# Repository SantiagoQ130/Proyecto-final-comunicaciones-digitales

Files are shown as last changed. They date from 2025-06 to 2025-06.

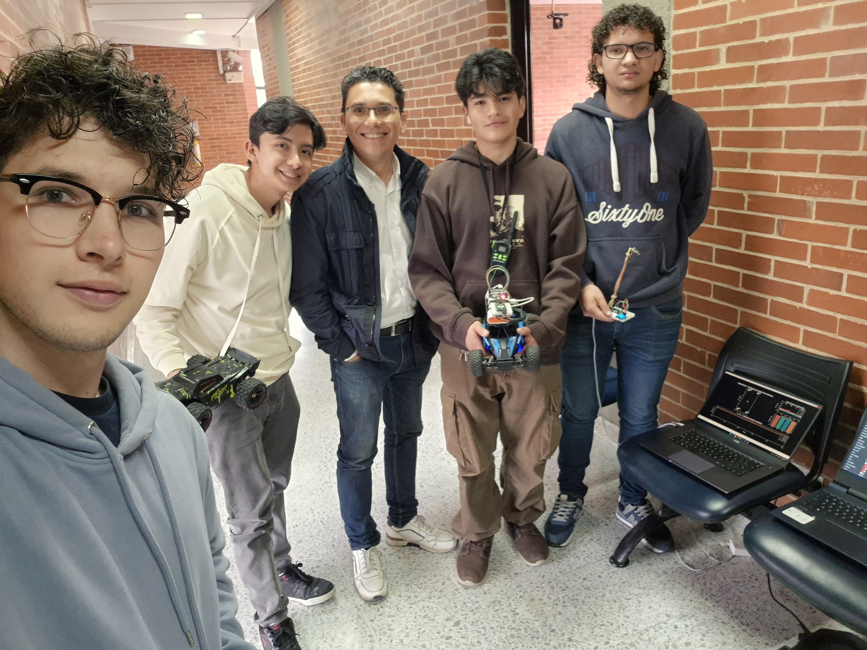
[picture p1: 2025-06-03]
Progreso/Foto.jpg

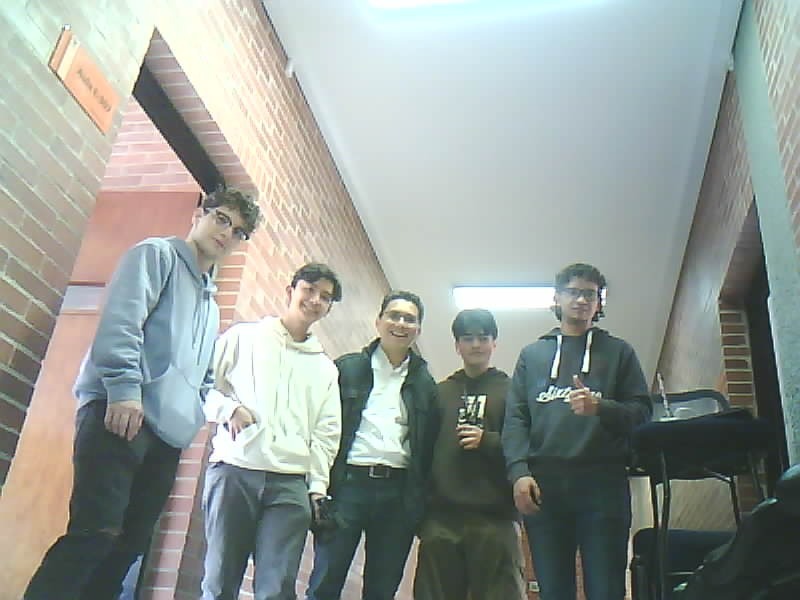
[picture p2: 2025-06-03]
Progreso/Foto carro.jpg

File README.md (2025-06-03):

# Sistema de Localización Indoor con RSSI y Sensores IMU

## 📋 Descripción del Proyecto

Este proyecto implementa un sistema de localización en interiores que utiliza mediciones de RSSI (Received Signal Strength Indicator) para determinar la posición de objetos móviles en espacios cerrados. El sistema combina múltiples tecnologías de comunicación inalámbrica para crear una red de nodos que permite la trilateración y el seguimiento de dispositivos.

## 🎯 Objetivos

- **Objetivo Principal**: Desarrollar un sistema de localización preciso para ambientes interiores donde GPS no está disponible
- **Objetivos Específicos**:
  - Implementar una red de nodos transmisores con comunicación RF (NRF24L01)
  - Crear un concentrador que recopile datos de RSSI de múltiples transmisores
  - Integrar sensores IMU 
  - Desarrollar algoritmos de trilateración para cálculo de posición
  - Crear una interfaz web para monitoreo en tiempo real

## 🏗️ Arquitectura del Sistema

### Componentes Principales

1. **Nodos Transmisores (TX1-TX4)**
   - Microcontroladores Raspberry Pi Pico W
   - Módulos NRF24L01 para comunicación RF
   - Pantallas OLED para visualización local
   - Medición de RSSI con dispositivos WiFi cercanos

2. **Concentrador/Receptor (RX)**
   - Raspberry Pi Pico W central
   - Recepción de datos de todos los transmisores
   - Procesamiento y análisis de datos RSSI
   - Interfaz de comunicación serial

3. **Nodo Principal con IMU**
   - Arduino R4 WiFi o ESP32
   - Sensor MPU6050 (acelerómetro + giroscopio)
   - Punto de acceso WiFi (Hotspot)
   - Servidor web integrado
   - Filtrado Kalman para datos del sensor
   - Esp-S3-N16R8(ESP32 S3 cam)
   - Servidor web para la camara con diferentes configuraciones
   - Reconocimiento facial

4. **Sistema de Procesamiento**
   - Algoritmos de trilateración
   - Análisis de datos en Python
   - Visualización en tiempo real

### Diagrama de Comunicación

```
[TX1] ──┐
[TX2] ──┼── NRF24L01 ──→ [RX/Concentrador] ──→ [PC/Análisis]
[TX3] ──┤                       ↕
[TX4] ──┘                   Serial/USB

[Nodo IMU] ──→ WiFi Hotspot ──→ [Dispositivos Cliente]
    ↓
[MPU6050 Sensor]
```

## 📁 Estructura del Proyecto

```
Proyecto-final-comunicaciones-digitales-main/
├── Códigos/                    # Código principal del sistema
│   ├── ArduinoR4_hotspot_MPU6050.ino    # Nodo principal con IMU
│   ├── RX_Concentrador.py               # Receptor central
│   ├── TX1.py, TX2.py, TX3.py, TX4.py  # Nodos transmisores
│   └── PicoW_Plotter_concentrador.py    # Visualización en tiempo real
├── Alternativas_hotspot/       # Implementaciones alternativas
│   ├── Esp32_hostpot.ino      # Versión ESP32
│   ├── Esp32_MPU6050_Basic.ino # ESP32 con MPU6050 básico
│   └── Esp32-s3-hotspot-mpu6050.ino # ESP32-S3 avanzado
├── Progreso/                   # Desarrollos incrementales
│   ├── trilateracion.py       # Algoritmo de trilateración
│   ├── basic_serial_reader.py # Lector serial básico
│   └── simple_serial_reader.py # Lector serial simplificado
├── datos/                      # Datos experimentales y mediciones
│   ├── Measure 1.txt          # Mediciones RSSI vs distancia
│   ├── Measure 2.txt          # Segunda serie de mediciones
│   ├── Medidas RSSI.xlsx      # Análisis estadístico
│   └── serial_reader_data.py  # Procesador de datos serie
├── Diseño PCB/                 # Diseño de PCB personalizada
│   ├── NUEVO_NODO-*.gbr       # Archivos Gerber
│   ├── NUEVO_NODO-*.drl       # Archivos de perforación
│   └── Simulación/            # Archivos de simulación
└── README.md                   # Este archivo
```

## 🛠️ Requisitos del Sistema

### Hardware Necesario

#### Para Nodos Transmisores (TX1-TX4):
- 4x Raspberry Pi Pico W
- 4x Módulo NRF24L01+
- 4x Pantalla OLED SSD1306 (128x64)
- Cables jumper y protoboard
- Fuente de alimentación 3.3V

#### Para Concentrador (RX):
- 1x Raspberry Pi Pico W
- 1x Módulo NRF24L01+
- 1x Pantalla OLED SSD1306 (128x64)
- Cable USB para conexión serial

#### Para Nodo Principal:
- 1x Arduino R4 WiFi o ESP32 DevKit
- 1x Sensor MPU6050 (acelerómetro + giroscopio)
- Cables jumper
- 1x Esp32-S3-N16R8
- 1x Camara Ov2640

#### Opcional - PCB Personalizada:
- PCB diseñada (archivos en `/Diseño PCB/`)
- Componentes SMD según esquemático

### Software Necesario

#### Para Microcontroladores:
- **Arduino IDE** (versión 2.0 o superior)
- **MicroPython** (para Raspberry Pi Pico W)
- **Librerías Arduino**:
  - WiFiS3 (Arduino R4)
  - ArduinoJson
  - MPU6050
  - Wire

#### Para Raspberry Pi Pico W:
- **Librerías MicroPython**:
  - nrf24l01
  - ssd1306
  - machine

#### Para Análisis (PC):
- **Python 3.7+**
- **Librerías Python**:
  ```bash
  pip install numpy matplotlib pyserial
  ```

## 🚀 Instalación y Configuración

### 1. Configuración de Nodos Transmisores

1. **Preparar Raspberry Pi Pico W**:
   ```bash
   # Instalar MicroPython en cada Pico W
   # Copiar archivos TX1.py, TX2.py, TX3.py, TX4.py
   ```

2. **Conexiones Hardware TX**:
   ```
   NRF24L01    Pico W
   --------    ------
   VCC      →  3.3V
   GND      →  GND
   SCK      →  GP2
   MOSI     →  GP3
   MISO     →  GP4
   CSN      →  GP5
   CE       →  GP6
   
   OLED        Pico W
   ----        ------
   VCC      →  3.3V
   GND      →  GND
   SDA      →  GP14
   SCL      →  GP15
   ```

3. **Configuración de Direcciones**:
   - Cada transmisor tiene una dirección única
   - TX1: `\xe1\xf0\xf0\xf0\xf0`
   - TX2: `\xc3\xf0\xf0\xf0\xf0`
   - TX3: `\xd2\xf0\xf0\xf0\xf0`
   - TX4: `\xb1\xf0\xf0\xf0\xf0`

### 2. Configuración del Concentrador (RX)

1. **Hardware**: Mismo conexionado que transmisores
2. **Software**: Cargar `RX_Concentrador.py`
3. **Configuración**: 
   - Canal RF: 10
   - Direcciones sincronizadas con transmisores

### 3. Configuración del Nodo Principal

#### Para Arduino R4 WiFi:

1. **Conexiones MPU6050**:
   ```
   MPU6050     Arduino R4
   -------     ----------
   VCC      →  3.3V
   GND      →  GND
   SDA      →  SDA (pin 11)
   SCL      →  SCL (pin 12)
   ```

2. **Cargar código**: `ArduinoR4_hotspot_MPU6050.ino`

3. **Configuración WiFi**:
   - SSID: "ArduinoR4-123456"
   - Password: "12345678"
   - IP: 192.168.4.1

## 💻 Uso del Sistema

### 1. Inicialización

1. **Encender nodos en orden**:
   ```
   1. Concentrador (RX) primero
   2. Nodos transmisores (TX1-TX4)
   3. Nodo principal (Arduino/ESP32)
   ```

2. **Verificar conexiones**:
   - LEDs indicadores en cada nodo
   - Mensajes en pantallas OLED
   - Monitor serie para debug

### 2. Monitoreo en Tiempo Real

#### Interfaz Web (Nodo Principal):
1. Conectar dispositivo a WiFi "ArduinoR4-123456"
2. Abrir navegador en `http://192.168.4.1`
3. Ver datos de IMU en tiempo real

#### Monitor Serial (Concentrador):
```python
# Ejecutar visualizador
python PicoW_Plotter_concentrador.py
```

### 3. Análisis de Datos

#### Trilateración:
```python
# Ejecutar algoritmo de localización
python trilateracion.py
```

#### Procesamiento de Mediciones:
```python
# Analizar datos RSSI
python serial_reader_data.py
```

## 📊 Resultados Experimentales

### Precisión del Sistema
- **Rango de operación**: 0-30 metros
- **Precisión típica**: ±2-3 metros
- **Tiempo de actualización**: 50ms (20Hz)
- **Número de nodos**: 4 transmisores + 1 receptor

### Datos de Calibración RSSI vs Distancia

| Distancia (m) | TX1 (dBm) | TX2 (dBm) | TX3 (dBm) | TX4 (dBm) |
|---|---|---|---|---|
| 0 | -40 | -52 | -52 | -42 |
| 5 | -76 | -81 | -79 | -78 |
| 10 | -77 | -77 | -75 | -72 |
| 15 | -69 | -71 | -70 | -80 |
| 20 | -81 | -84 | -82 | -75 |

### Características del Sensor IMU
- **Acelerómetro**: ±2g, ±4g, ±8g, ±16g
- **Giroscopio**: ±250°/s, ±500°/s, ±1000°/s, ±2000°/s
- **Filtrado**: Kalman con Q=0.001, R=0.01
- **Frecuencia de muestreo**: 50Hz

## 📝 Notas

- Utilizamos power banks para energizar continuamente los sistemas.

## 🔧 Troubleshooting

### Problemas Comunes

#### 1. NRF24L01 no comunica:
```
Solución:
- Verificar alimentación 3.3V (no 5V)
- Revisar conexiones SPI
- Comprobar distancia entre módulos
- Verificar canal RF (debe ser igual en TX/RX)
```

#### 2. MPU6050 no responde:
```
Solución:
- Verificar conexiones I2C
- Comprobar dirección I2C (0x68 o 0x69)
- Realizar calibración inicial
- Verificar voltaje de alimentación
```

#### 3. WiFi no se conecta:
```
Solución:
- Verificar SSID y password
- Comprobar canal WiFi libre
- Reiniciar módulo WiFi
- Verificar antena conectada
```

### Comandos de Debug

```cpp
// En Arduino IDE - Monitor Serie
Serial.println("DEBUG: Estado del sistema");

// Verificar NRF24L01
nrf.printDetails();

// Estado MPU6050
Serial.print("MPU6050 ID: ");
Serial.println(mpu.getDeviceID());
```

## 🔬 Trabajo Futuro

### Mejoras Propuestas

1. **Algoritmos Avanzados**:
   - Implementar filtros de partículas
   - Fusión de sensores con filtro Kalman extendido
   - Machine Learning para calibración automática

2. **Hardware**:
   - PCB definitiva con componentes optimizados
   - Antenas direccionales para mejor RSSI
   - Batería recargable integrada

3. **Software**:
   - Interfaz web más avanzada
   - Base de datos para histórico
   - API REST para integración externa

4. **Escalabilidad**:
   - Soporte para más nodos
   - Mesh networking
   - Localización multi-piso

## 👥 Contribuidores

- **Desarrolladores**: [Rafael Garzon, Guillermo Hernandez, Sebastian Restrepo, Edgar Quiroz]
- **Proyecto**: Trilateracion indoor
- **Institución**: Universidad Militar Nueva Granada
- **Fecha**: Junio 2025

## 📚 Referencias

1. Zafari, F., Gkelias, A., & Leung, K. K. (2019). A survey of indoor localization systems and technologies. IEEE Communications Surveys & Tutorials.

2. Yasir, M., Ho, S. W., & Vellambi, B. N. (2016). Indoor positioning system using visible light and accelerometer. Journal of Lightwave Technology.

3. Arduino Reference Documentation: https://docs.arduino.cc/

4. Raspberry Pi Pico Documentation: https://datasheets.raspberrypi.org/pico/

---

**¡Gracias por usar nuestro Sistema de Localización Indoor!** 🎯📡

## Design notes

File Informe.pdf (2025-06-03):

# Laboratorio:

# Proyecto final

Estudiantes:
Edgar Santiago Quiroz Puentes Rafael Alejandro Garzon Andosilla Sebastian Restrepo Sanchez Guillermo Antonio Hernandez Ortiz est.edgar.squiroz@unimilitar.edu.co est.rafael.agarzon@unimilitar.edu.co est.sebastian.rest@unimilitar.edu.co est.guillermo.hern@unimilitar.edu.co

Profesor:
Jose de Jesus Rugeles Uribe jose.rugeles@unimilitar.edu.co

Universidad Militar Nueva Granada Bogotá, (3/Junio/2025)

I. INTRODUCCIÓN
La necesidad de conocer la ubicación precisa de personas u objetos en espacios cerrados ha impulsado el desarrollo de tecnologías de localización indoor. A diferencia del posicionamiento GPS, que pierde precisión en entornos cerrados, los sistemas basados en mediciones de señal inalámbrica ofrecen una solución efectiva. Este proyecto tiene como objetivo diseñar e implementar un sistema de localización en tiempo real mediante trilateración inalámbrica en los espacios cerrados de la universidad.

II. OBJETIVO GENERAL
Desarrollar un sistema funcional de localización en interiores que utilice mediciones de RSSI desde múltiples nodos, empleando técnicas de trilateración, para determinar en tiempo real la posición de un nodo móvil en un entorno con obstáculos.

III. OBJETIVOS ESPECIFICOS
- Aprender a utilizar la trilateración usando como base el RSSI de 4 nodos fijos.
- Explorar los diferentes tipos de comunicación WiFi
para | diferentes | proyectos | de | comunicación
inalámbrica.
- Comprender los diferentes protocolos y sus diferencias de comunicación WiFi.

IV. ESTADO DEL ARTE
La tecnología de posicionamiento en interiores se ha convertido en un campo de investigación creciente en la moderna tecnología de las comunicaciones debido a la necesidad de localizar equipos o personas en espacios donde los Sistemas de Posicionamiento Global (GPS) no pueden operar. A diferencia del GPS, que funciona con precisión en espacios abiertos, las señales de los satélites se ven considerablemente atenuadas por techos, paredes y obstáculos típicos de los entornos cerrados. Por eso se han desarrollado soluciones alternativas basadas en tecnologías de corto alcance como WiFi, Bluetooth, ZigBee y RF propietaria, cada una con su propio método de estimación de distancia o posición.

Desde entonces, se han propuesto diversas mejoras del uso de RSSI, como el filtrado, el modelado adaptativo y la combinación con otros sensores. Por ejemplo, Liu et al. (2007) realizaron una revisión sistemática de las técnicas de localización en interiores y las clasificaron según su precisión, escalabilidad y facilidad de implementación. El RSSI se caracteriza por su bajo coste y su compatibilidad con las redes inalámbricas existentes; sin embargo, su precisión puede verse afectada por fenómenos como el desvanecimiento, las reflexiones múltiples y las interferencias electromagnéticas, especialmente en entornos obstruidos.

En cuanto a las tecnologías disponibles, se han explorado varias alternativas. Bluetooth Low Energy (BLE) se utiliza ampliamente para el seguimiento de la ubicación en tiendas, museos y centros comerciales, principalmente debido a su bajo consumo de energía y compatibilidad con dispositivos móviles; sin embargo, estudios como el de Faragher y Harle (2015) han demostrado que la estabilidad RSSI de BLE puede degradarse en entornos dinámicos, lo que resulta en una baja precisión sin filtros adicionales. Por otro lado, tecnologías como la banda ultra ancha (UWB) ofrece una precisión mucho mayor, pero a costa de un elevado coste y de la necesidad de equipos especializados. En este contexto, sistemas modulares como el NRF24L01, que opera en la banda ISM de 2,4 GHz, representan una solución intermedia viable. El sistema es capaz de medir RSSI, tiene un bajo consumo de energía, buenas velocidades de transmisión de datos (hasta 2 Mb/s) y puede integrarse fácilmente con microcontroladores como el Raspberry Pi Pico W.

Por tanto, la selección del protocolo y los módulos para este proyecto se basó en un compromiso entre precisión, coste, disponibilidad y escalabilidad. El módulo NRF24L01 se eligió principalmente por su capacidad para ejecutar varios nodos
simultáneamente, | crear | canalizaciones | de | recepción
independientes, su bajo consumo de energía y su integración inherente con el entorno de programación MicroPython. Además, su uso en combinación con sensores inerciales (como el MPU6050) y cámaras ESP32CAM con reconocimiento facial permite ampliar el sistema no sólo para la detección, sino también para el reconocimiento visual del nodo móvil, ampliando las aplicaciones en sistemas de seguridad, vigilancia y automatización.

Por último, es importante mencionar el papel del software en el tratamiento y la visualización de datos. Herramientas como Python y MATLAB son ampliamente utilizadas para implementar modelos de propagación, filtrar señales y calcular la localización. El proyecto presentado por Rúgeles(2024), cuyo código está disponible en GitHub, muestra una arquitectura completa para NRF24L01, Raspberry Pi Pico y cálculo de RSSI en tiempo real, que puede servir de referencia para el desarrollo de este proyecto.

En general, aunque hay muchas tecnologías y métodos disponibles en el entorno interior, el uso de RSSI en combinación con los módulos NRF24L01 representa una
solución | práctica | y | comercial en | un | entorno | real.
Particularmente su alta precisión, su facilidad de uso y flexibilidad lo hacen especialmente adecuado para aplicaciones educativas y modelos de trabajo con presupuestos bajos.
V. METODOLOGÍA
A. Preparación
Se comenzó con el planeamiento del proyecto al elegir los materiales que se necesitarían utilizar. Para armar los 5 nodos fue necesario contar con una raspberry pi-pico W, un módulo con antena NRF24L01 y una pantalla OLED de 28x64.

Cuatro de estos nodos fueron programados para conectarse a un Access Point (AP) y en la pantalla mostrar las mediciones en tiempo real del RSSI que reciben de este, además sería energizado con una batería de 9V, con la ayuda de un módulo fuente MB102 o directamente con una batería portátil.

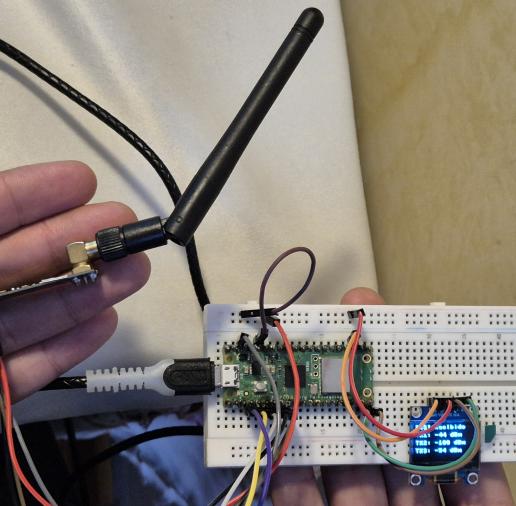
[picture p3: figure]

Ilustración 1. Montaje de los nodos

El quinto nodo fue apodado como “Receptor”, el cual está programado para el recibimiento en tiempo real de los datos enviados desde los otros nodos por medio de la programación en MycroPython conocida como “pipes”, de esta forma múltiples comunicaciones pueden ocurrir simultáneamente en eta raspberry.

El AP (Access point) fue armado utilizando un ESP-CAM, un giroscopio MPU5060 y un segundo ESP32. Este montaje, al ser energizado podrá brindar una red WiFi para que diferentes hosts (nodos) se puedan conectar y poder rastrear su movimiento.

Este módulo fue montado sobre un carro a control remoto proporcionado por el profesor para poder demostrar el cambio en tiempo real del RSSI en cada nodo. Fue instalado en el techo del carro, siendo energizado con una batería de 9V, sujetado con velcro para evitar incidentes como daños al módulo.

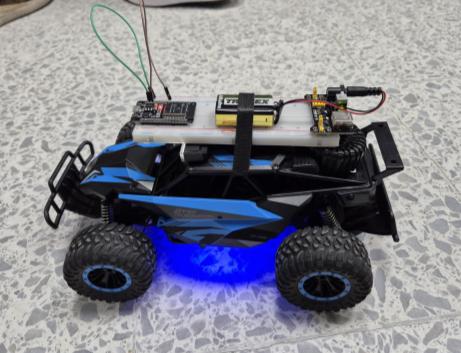
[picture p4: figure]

Ilustración 2. Montaje inicial del AP

B. Programación de los dispositivos
Se desarrollaron varios códigos para lograr el objetivo del laboratorio que fueron probándose y aplicándose al tiempo que se desarrollaban las pruebas.

Los tres primeros códigos implementados en el proyecto corresponden a los nodos transmisores llamados TX2, TX3 y TX4. Su función principal es la de capturar el valor de intensidad de la señal RSSI, promediarlo, visualizarlo localmente en una pantalla OLED y enviarlo de forma inalámbrica mediante un módulo NRF24L01 al nodo concentrador.

A nivel funcional, los tres códigos comparten la misma estructura y lógica general. Inician estableciendo conexión con la red WiFi configurada, miden la intensidad de la señal utilizando el método “wifi.status('rssi')”. Calculan un promedio móvil basado en las últimas diez mediciones para reducir fluctuaciones, y transmiten el resultado junto con un identificador único mediante el protocolo NRF24L01. Además, todos utilizan el mismo esquema de pines para la conexión SPI del transceptor y para la interfaz I2C del display OLED SSD1306, donde se muestra el identificador del nodo, el nombre de la red, la IP local asignada y el valor del RSSI promedio.

Sin embargo, aunque estos códigos son prácticamente idénticos en su estructura, presentan pequeñas diferencias fundamentales que permiten distinguirlos entre sí. La primera diferencia está en el identificador del nodo transmisor (`TX_ID`), que varía entre 2, 3 y 4 según el nodo. Este valor se incluye en el paquete de datos enviado, permitiendo que el receptor identifique el origen de la medición.

La segunda diferencia se encuentra en la dirección del canal de transmisión (`TX_ADDRESS`) asignada a cada nodo; cada uno posee una dirección única, lo cual garantiza que no haya interferencia entre ellos y que el receptor pueda manejar múltiples transmisiones sin ambigüedad. Finalmente, cada nodo muestra en su pantalla OLED su nombre respectivo, de esta manera se permite una rápida identificación visual en el entorno de pruebas. Estas diferencias, aunque mínimas, son cruciales para la correcta operación del sistema, ya que aseguran la independencia y trazabilidad de las señales emitidas por cada transmisor dentro del sistema de localización en interiores.

El código implementado para el funcionamiento del nodo receptor NRF24L01 cumple la función de centralizar y gestionar la recepción de los datos enviados por los transmisores. Su tarea principal es escuchar continuamente el canal de comunicación inalámbrica configurado (canal 10), identificar el transmisor del cual proviene cada mensaje, extraer la información correspondiente al valor de RSSI promedio, y mantener un historial actualizado de estas mediciones. Al igual que los transmisores, este código utiliza comunicación SPI para interactuar con el módulo NRF24L01 y conexión I2C para mostrar los valores en una pantalla OLED SSD1306.

La lógica del receptor se basa en el uso de las “pipes” de recepción con las direcciones únicas asignadas a cada transmisor. A medida que se reciben datos, el receptor los desempaca utilizando “struct.unpack”, actualiza el historial de valores RSSI por nodo y registra el tiempo en que se recibió la última transmisión. Si uno de los transmisores deja de enviar datos durante más de 40 segundos, el sistema detecta un llamado “timeout” y restablece su valor RSSI a -100 dBm como medida de advertencia indicando su desconexión, así se puede identificar rápidamente interrupciones en la comunicación.

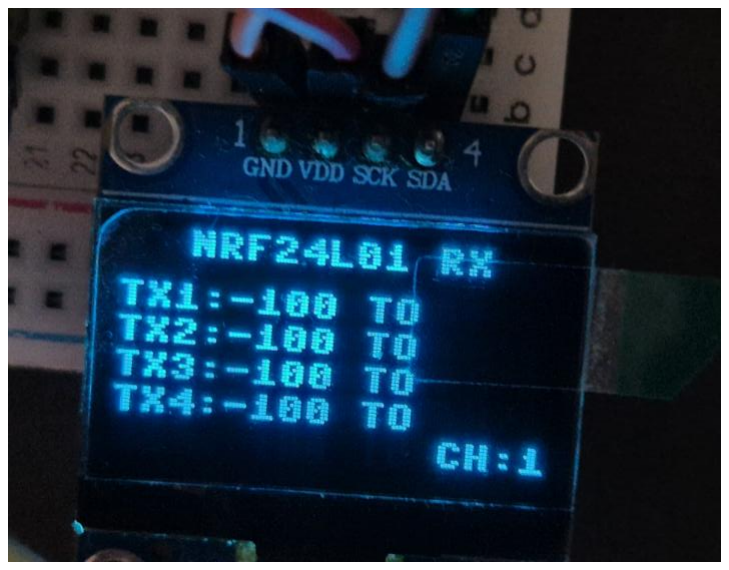
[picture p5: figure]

Ilustración 3. Nodo receptor sin conexión

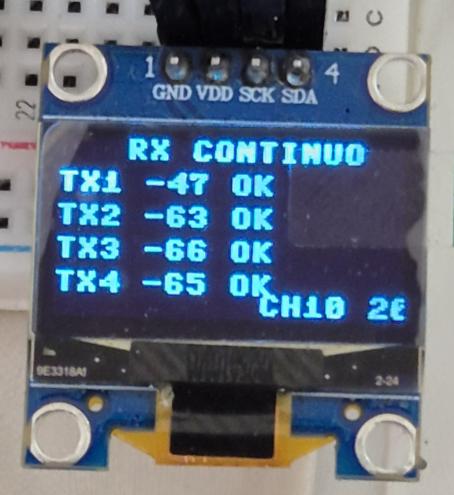
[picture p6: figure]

Ilustración 4. Nodo receptor conectado

El receptor también se encarga de enviar los datos procesados al computador central en formato JSON, lo cual facilita su lectura y análisis mediante herramientas externas o scripts de visualización. Adicionalmente, en cada iteración del ciclo principal, el sistema actualiza la pantalla OLED con los valores RSSI actuales de cada transmisor, lo cual permite un monitoreo en tiempo real del comportamiento del sistema.

Se hizo un código con el propósito visualizar en tiempo real las mediciones RSSI enviadas por los nodos transmisores y recolectadas por el nodo receptor. Para ello, el sistema utiliza una conexión serial entre la computadora y el receptor por medio de un puerto USB, a través de la cual se reciben continuamente los datos formateados en JSON que contienen los valores RSSI de los transmisores TX1 a TX4.

La lógica del programa se basa en el uso de la biblioteca matplotlib, junto con su módulo de animación, para crear una gráfica dinámica que se actualiza constantemente conforme llegan nuevas mediciones. Internamente, el código mantiene un historial de los últimos 100 puntos por cada transmisor, lo que permite observar la evolución de la señal de cada nodo sin saturar la memoria ni sobrecargar la visualización.

Al iniciar, el script abre el puerto serial especificado con una velocidad de baudios de 115200. Luego, entra en un bucle

controlado | por | “FuncAnimation”, | el | cual | ejecuta
periódicamente una función encargada de leer nuevas líneas del puerto.

Cada transmisor tiene asignado un color distinto: rojo para TX1, verde para TX2, azul para TX3 y naranja para TX4. Se visualizan simultáneamente en una misma figura, permitiendo comparar en tiempo real la intensidad de señal relativa entre los nodos. La escala del eje Y está configurada para mostrar valores típicos de RSSI entre -110 y -20 dBm, mientras que el eje X representa el número de muestras recientes.

El sistema es fundamental para el análisis y la validación visual del comportamiento del sistema de localización, ya que permite observar en tiempo real cómo varía la señal de cada transmisor con respecto al movimiento del nodo móvil, facilitando la depuración, la interpretación de resultados y la verificación experimental del modelo de propagación.

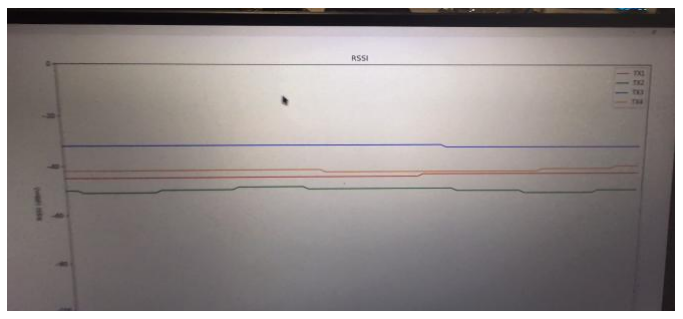
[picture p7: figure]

Ilustración 5. Sistema de visualización en tiempo real

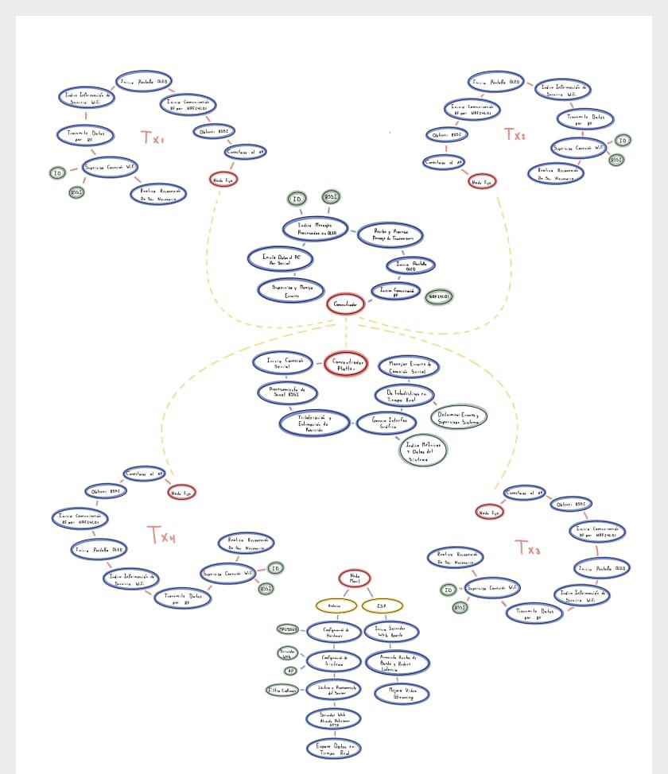
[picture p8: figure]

Ilustración 6. Diagrama del funcionamiento del código

C. PCB
Se hizo el proceso para presentar los nodos en una placa de PCB para hacer más cómoda la transportación y disposición de estos a la hora de hacer las pruebas. Se utilizó la herramienta de KiCad para esta tarea, gracias a esta y sus múltiples bibliotecas de dispositivos se pudo hacer un diagrama esquemático del proyecto. Debido al uso de dispositivos específicos como la pantalla y el módulo fuente, estos no contaban con bibliotecas dentro de la aplicación por lo que se tuvo que hacerlas desde cero, haciendo su esquemático y luego su huella.

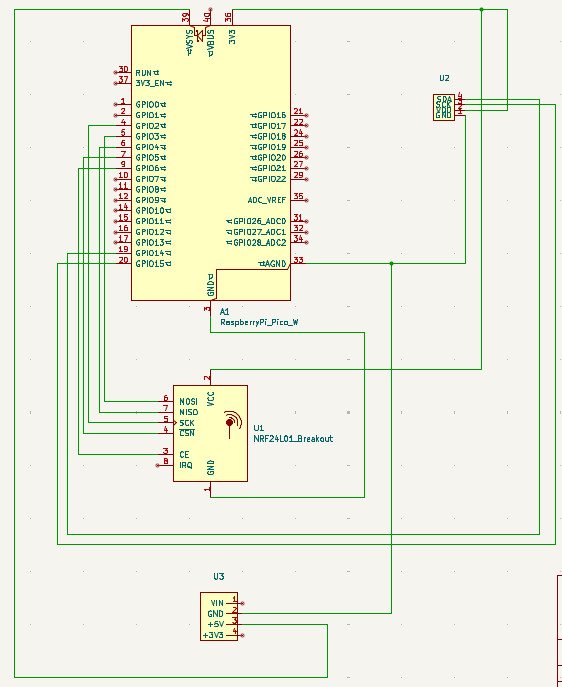
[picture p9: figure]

Ilustración 7. Diseño esquemático

La disposición de los pines se puede ejemplificar de mejor forma en un diseño más práctico.

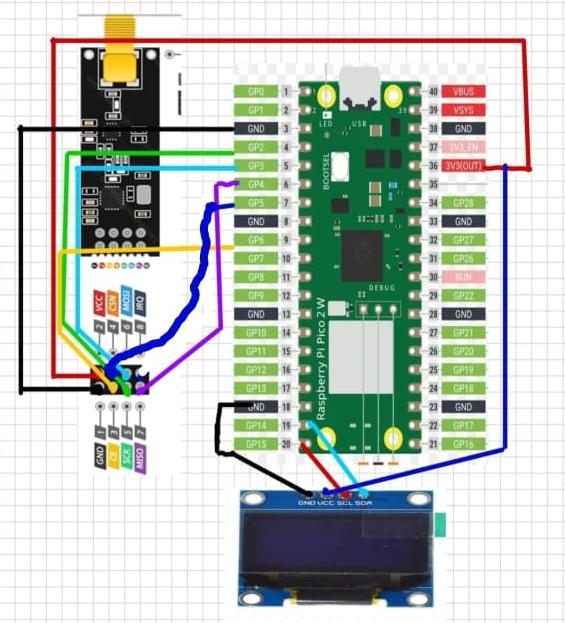
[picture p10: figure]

Ilustración 8. Diseño práctico

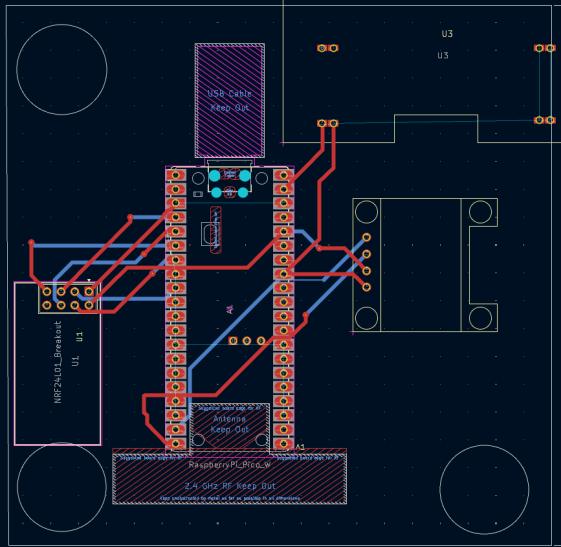
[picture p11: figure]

Ilustración 9. Diseño de la PCB

El diseño muestra una disposición de los elementos para que quepa dentro de una placa, hay tracks en color rojo que representan las líneas de conexión que se encuentran en la cara superior de la PCB y las líneas azules serían los tracks en la cara inferior de cobre, de esta forma se puede comprimir más el diseñó ya que los tracks rojos se pueden sobreponer y no afectar a los tracks azules.

Se envió el diseño a una empresa dedicada a esto, pero por disposición de esta no fue posible tenerla a tiempo para las pruebas y la presentación de proyecto, por lo que se optó por el uso de baquelitas y soldar el diseño por medio propios.

Se imprimió la cara superior y luego la cara inferior (en forma espejo) en papel termotransferible con la ayuda de una impresora láser y se hizo el proceso de planchado para tener al menos un nodo montado en PCB. Los demás nodos, por comodidad y tiempo, fueron solados en baquelitas.

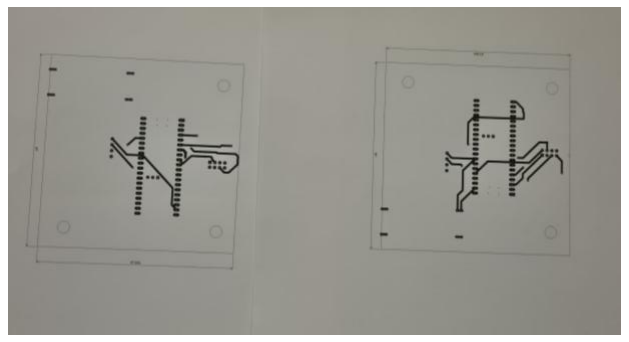
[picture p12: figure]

Ilustración 10. Impresiones de PCB

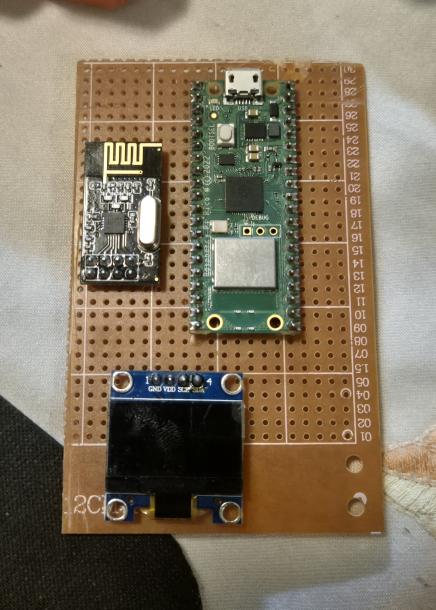
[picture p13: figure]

Ilustración 11. Nodo montado en váquela

En este proceso se pudo evidenciar que la realización de PCB con métodos caseros puede resultar afectada por la imprecisión de la mano humana, además, la aplicación del proceso con materiales rústicos genera grandes problemas cuando se desea imprimir pistas o guías de un tamaño considerable en un entorno con espacio limitado por los módulos, la disposición de los componente también resultan en complicaciones si se tiene en cuenta el tamaño necesario de los pads para realizar la transición entre las dos caras del circuito.

Ya que el proceso anterior no consiguió cumplir con las expectativas para solucionar el inconveniente de practicidad, se optó por realizar la conexión de los componentes de cada nodo por medio de una baquelita universal, sin embargo, los resultados no fueron para nada los esperados.

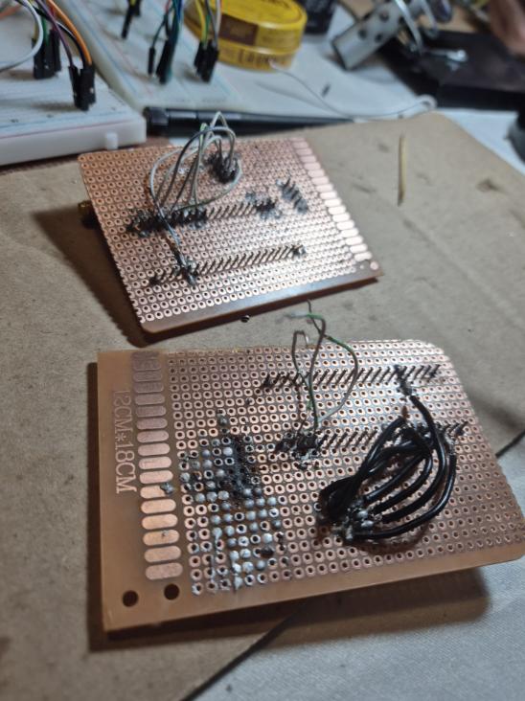
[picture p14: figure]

Ilustración 12. Prototipo de váquelas

En un principio el proceso resultó ser adecuado, pues se optimizaba el espacio y el funcionamiento del dispositivo, sin embargo, poco después al realizar las pruebas correspondientes, los nodos comenzaron a fallar de forma inesperada si opción de arreglo aparente, por lo que se optó por realizar las pruebas mediante la disposición aplicada al principio del desarrollo del laboratorio.

D. Nodo móvil
Se compone de un Arduino r4 (ESP32s3mini), un MPU6050 (giroscopio) y un ESP32-CAM. Se utilizaron hasta 4 tipos diferentes de AP: un ESP simple con una antena integrada en la PCB, luego se modificó para integrarle una antena, después de que el diseño no fuera plausible luego de un daño considerable, se optó por migrar a un microcontrolador esp32s3 mini que de mejores resultados en relación en alcance e intensidad.

El giroscopio ha sido controlado por la misma placa de desarrollo que genera el AP, el ESP32-CAM es capaz de reconocer la cara de algunos de los integrantes del grupo.

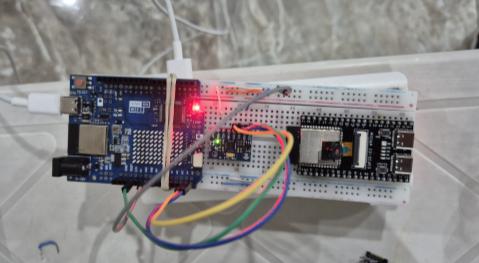
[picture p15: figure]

Ilustración 13. Nodo móvil

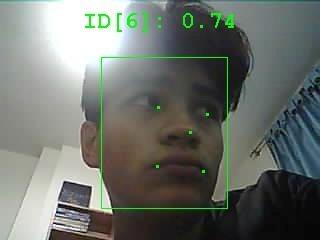
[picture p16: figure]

Ilustración 14. Prueba de reconocimiento facial

E. Protocolos utilizados
En el diseño e implementación de cada nodo del sistema, se emplearon distintos protocolos de comunicación digital que permiten la interacción eficiente entre los componentes. Uno de los principales utilizados es I2C (Inter-Integrated Circuit), empleado para la comunicación con la pantalla OLED. Este protocolo serial síncrono se caracteriza por su simplicidad y eficiencia, al requerir únicamente dos líneas para establecer la comunicación entre múltiples dispositivos:
- La línea SDA (Serial Data Line) se encarga del intercambio de datos bidireccional.
- La línea SCL (Serial Clock Line) proporciona la señal de reloj que sincroniza la transferencia de datos.

I2C resulta particularmente adecuado en este proyecto debido a la baja cantidad de pines disponibles en los microcontroladores utilizados, así como por el volumen relativamente reducido de datos que se intercambian con el display. Durante las pruebas, mediante la herramienta Logic, se monitorearon las líneas del protocolo, evidenciándose una transmisión continua de bits sobre SDA y una señal de reloj estable y regular sobre SCL, lo cual confirma el correcto funcionamiento de la comunicación I2C.

Ilustración 15. Monitoreo en la herramienta Logic

Por otro lado, el módulo NRF24L01 utiliza el protocolo SPI (Serial Peripheral Interface) para comunicarse con el microcontrolador. Este protocolo, también serial y síncrono, se eligió debido a su alta velocidad y fiabilidad, fundamentales para el manejo de paquetes de datos en tiempo real. En la implementación, se utilizaron las siguientes líneas:

- CE (Chip Enable), específica del NRF24L01, para alternar entre modos de transmisión y recepción.
- CSN (Chip Select Not), que habilita la comunicación con el esclavo cuando está en nivel bajo.
- SCK (Serial Clock), que genera los pulsos de reloj para sincronizar la transferencia.
- MOSI (Master Out Slave In), que transmite datos desde el maestro al esclavo.
- MISO (Master In Slave Out), que transmite datos desde el esclavo al maestro.

Ilustración 16. Protocolo SPI

El análisis de las señales SPI también se realizó mediante monitoreo digital. Se observó que la línea CE permanece en bajo la mayor parte del tiempo, con breves pulsos en alto, coherentes con las fases de escritura y lectura del módulo. La línea CSN mostró ciclos repetitivos de activación (nivel bajo) y desactivación (nivel alto), correspondientes a las diferentes transacciones SPI. Durante estos períodos, se detectó una señal de reloj limpia en SCK y tráfico activo en las líneas MOSI y MISO, confirmando una comunicación bidireccional exitosa entre el microcontrolador y el transceptor.

F. Pruebas
Se comenzaron las pruebas para determinar el alcance que el AP en campo abierto, para esto se utilizó un metro laser desde un punto fijo y se midió hasta qué punto la conexión entre el nodo y el AP era estable. Para esto se conectaron baterías portátiles para energizar los módulos.

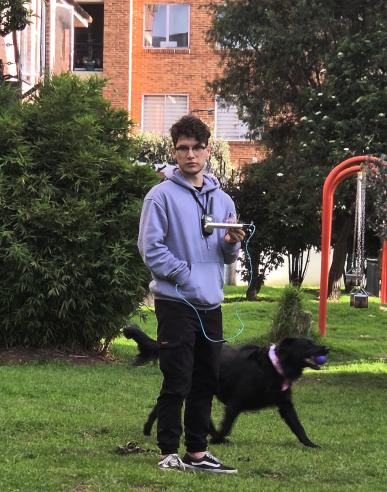
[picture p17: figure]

Ilustración 17. Prueba de distancia

Se llegó a una distancia de 48.6metros con un RSSI de -85dB antes de perder conexión, esto deja ver el alcance que tiene el AP utilizado

Los siguiente fue un ambiente mixto utilizando un decámetro para medir la magnitud del RSSI de cada uno de los nodos utilizando ambos APs para decidir el mejor para el uso de la práctica.

Ilustración 18. Prueba de distancia mixta

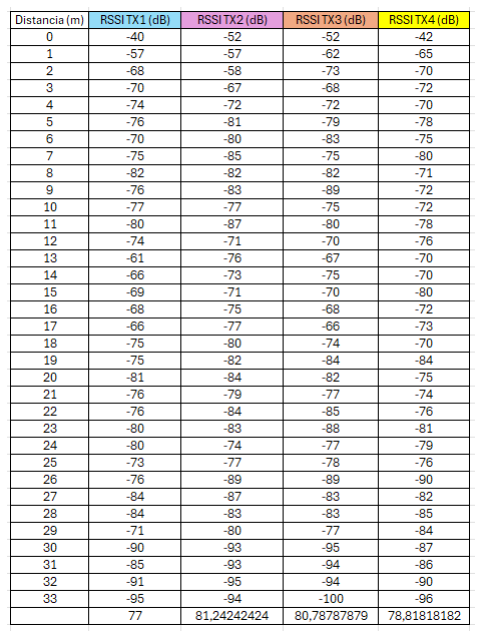
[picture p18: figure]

Ilustración 19. Datos del Arduino r4

Con el Arduino r4 se obtuvieron valores variantes, pero constantes sin desconectarse ninguno de los nodos.

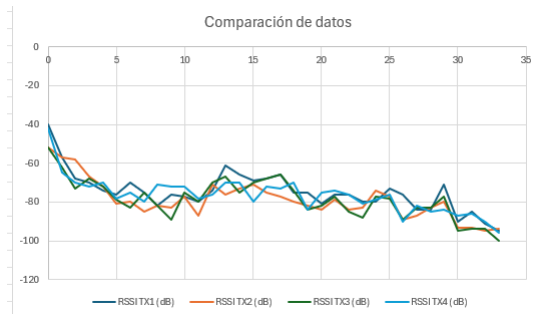
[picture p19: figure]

Ilustración 20. Comparación de los nodos

Se puede ver que el TX2, o la línea naranja tiene un movimiento más suave que indica una mejor recepción del AP, posiblemente por contar con modulo NRF mejor o por una mejor alineación frente al AP al hacer la medición.

Los nodos TX1 y TX4 presentan las peores estadísticas al tener alta tasa de fluctuación, es posible debido a una mala orientación de la bandera, un problema de alimentación o directamente un error en el software o hardware. Tx4 presentó problemas para conectarse al AP desde el inicio de la prueba, por lo esto puede ser una razón para su bajo rendimiento.

Ahora utilizando el AP compuesto por el ESP32 MPU6050 se encontraron datos muy diferentes.

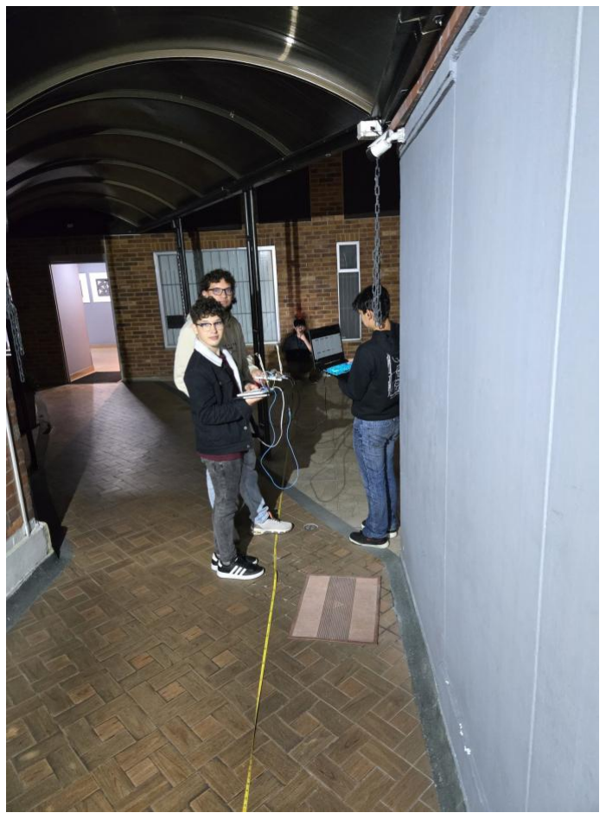
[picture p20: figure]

Ilustración 21.Segunda prueba

Ilustración 22. Datos de la segunda prueba

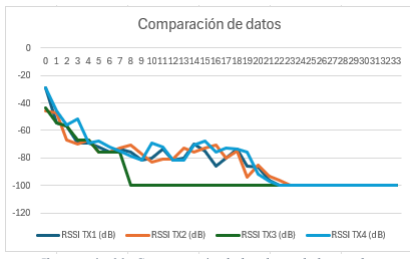
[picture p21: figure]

Ilustración 23. Comparación de los datos de la prueba

En esta prueba se vio como TX3, a pesar de tener un rendimiento promedio frente a los demás nodos fue el primero en perder la señal a los 8 metros, seguido del TX4, TX1 y TX1.

La desconexión repentina y a corto plazo de los nodos da a entender que el segundo AP no será la mejor opción para utilizar debido a que los nodos no pueden llegar muy lejos sin desconectarse. Además de que antes del inicio de la prueba TX3 y TX4 presentaron problemas para emparejarse correctamente al AP retrasando la prueba al tener que revisar sus códigos en busca de algún error en a la hora de conectase.

Se hizo ahora la prueba de trilateración en un espacio de 4.9m X 15.4m distribuyendo los nodos en esquinas de un cuadrado con el nodo receptor en el centro y el AP dando vueltas alrededor.

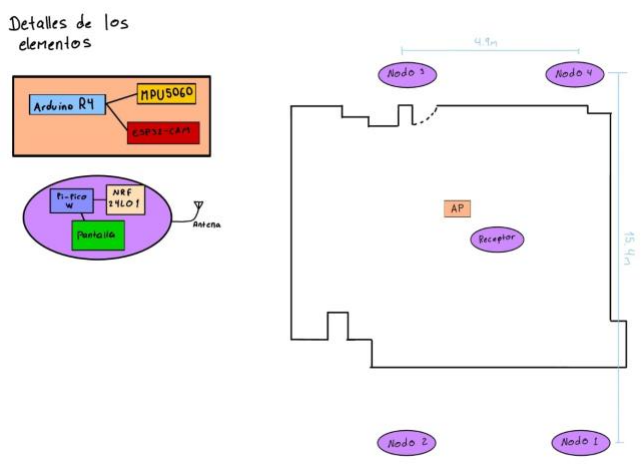
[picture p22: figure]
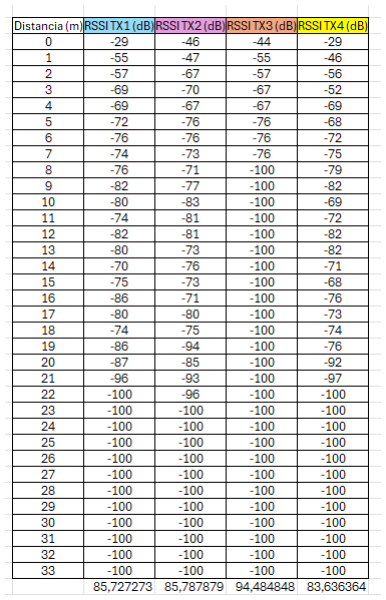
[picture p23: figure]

Ilustración 24. Plano de las pruebas

El codigo que se hizo para registrar la trilateración al mover el AP por el lugar muestra la localización en tiempo real, registro de la tasa de recepción y las distancias que separan los nodos del AP.

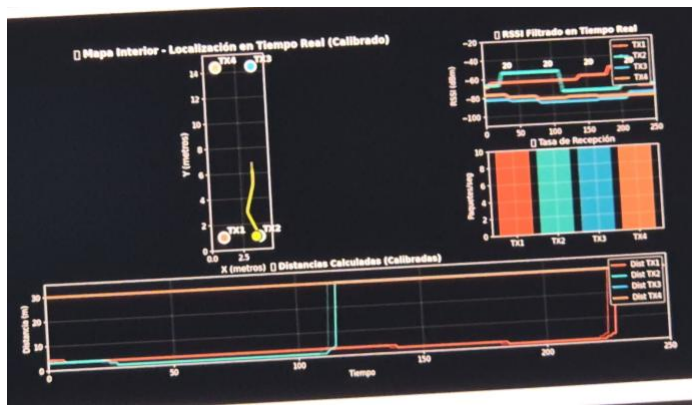
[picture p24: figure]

Ilustración 25. Interfaz de trilateración

El punto amarillo sigue el movimiento del AP dentro del perímetro de prueba dejando su trayectoria anterior marcada, muestra la forma en que el AP se acerca o aleja de los nodos, el mayor problema de la interfaz resulta ser que el punto amarillo no se mueve en tiempo real, lo que causa que sea necesario esperar unos instantes a que comience a moverse como lo hace el AP verdadero, el cual debe estar en movimiento continuo para evitar que el punto se mueva en cualquier dirección.

También se hizo un servidor web con el cual se puedan registrar datos del nodo móvil como el giroscopio, la orientación, su aceleración, además de los clientes (nodos) conectados actualmente.

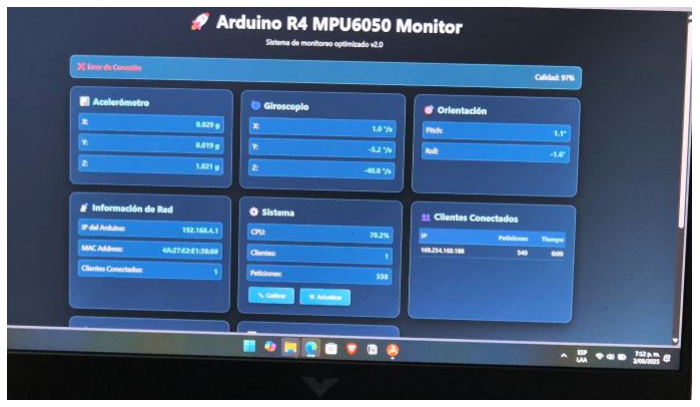
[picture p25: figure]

Ilustración 26. Servidor web

G. Trilateración en el proyecto
El espació decidido fue el interior del edificio de la universidad, se tomó el pasillo y 4 salones. Se tomaron las medidas y se repitieron las pruebas, ahora utilizando un carrito a control remoto para lograr el movimiento del AP a lo largo del escenario.

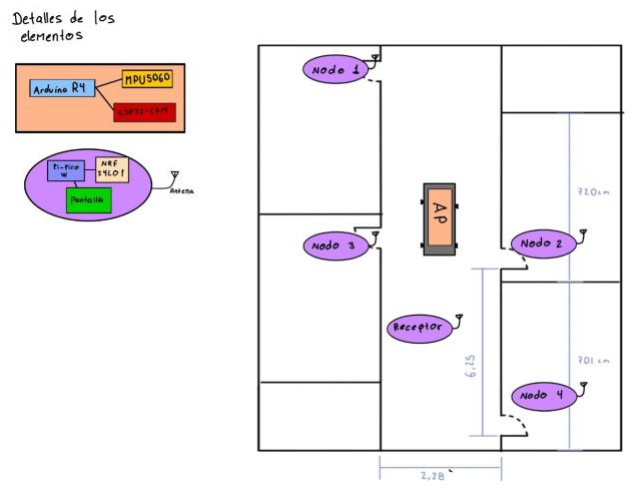
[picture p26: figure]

Ilustración 27. Plano del escenario

Al interactuar en entornos cerrados del establecimiento universitario, se pudo evidenciar que los obstáculos como son las paredes de amplio grosos, afectan en gran medida la propagación de las señales, además, las líneas de corriente distribuida por el establecimiento, que generan campos magnéticos, podrían ser una causa adicional de los problemas de conexión.

En resumen, la trilateración es el mecanismo que articula todos los elementos del sistema: los datos RSSI obtenidos por los transmisores fijos, la comunicación inalámbrica establecida por los módulos NRF24L01, y el procesamiento centralizado en Python. Esta integración nos permitió construir un sistema funcional y modular de localización indoor, capaz de seguir el desplazamiento del nodo móvil con una resolución suficiente para su análisis y evaluación en un entorno educativo y práctico.

H. Video
https://youtu.be/0HrP9MCD90s
I. Repositorio
https://github.com/SantiagoQ130/Proyecto-final-comunicaciones-digitales.git (https://github.com/SantiagoQ130/Proyecto-final-comunicaciones-digitales.git)
J. Concluciones
- El sistema de localización en interiores basado en RSSI y trilateración demostró ser funcional y replicable, permitiendo estimar la posición del nodo móvil con una resolución adecuada para aplicaciones educativas y prácticas.
- La calidad de recepción de cada transmisor depende no solo de la distancia al nodo móvil, sino también de factores físicos como la orientación de las antenas, la interferencia ambiental y la estabilidad del hardware, lo cual se evidenció en el comportamiento desigual de los nodos durante las pruebas.
- La latencia observada en el sistema, tanto en la transmisión de datos desde los transmisores como en su procesamiento en el nodo receptor, afectó la precisión del posicionamiento en tiempo real. Este desfase provocó que la ubicación estimada del nodo móvil no siempre coincidiera con su posición actual, especialmente durante desplazamientos rápidos, lo que resalta la necesidad de optimizar la frecuencia de actualización y la eficiencia del protocolo de comunicación.

REFERENCIAS

[1] ¿ Bahl, P., & Padmanabhan, V. N. (2000). RADAR: An in-building RF-based user location and tracking system. Proceedings IEEE INFOCOM 2000. Conference on Computer Communications. Nineteenth Annual Joint Conference of the IEEE Computer and Communications Societies (Cat. No.00CH37064), 2, 775–784. https://doi.org/10.1109/INFCOM.2000.832252
[2] Liu, H., Darabi, H., Banerjee, P., & Liu, J. (2007). Survey of wireless indoor positioning techniques and systems. IEEE Transactions on

Systems, Man, and Cybernetics, Part C (Applications and Reviews), 37(6), 1067–1080. https://doi.org/10.1109/TSMCC.2007.905750
[3] Faragher, R., & Harle, R. (2015). Location fingerprinting with Bluetooth Low Energy beacons. IEEE Journal on Selected Areas in
Communications, | 33(11), | 2418–2428.
https://doi.org/10.1109/JSAC.2015.2430281
[4] Zafari, F., Gkelias, A., & Leung, K. K. (2019). A survey of indoor localization systems and technologies. IEEE Communications
Surveys | & | Tutorials, | 21(3), | 2568–2599.
https://doi.org/10.1109/COMST.2019.2911558
[5] Rugeles, J. (2024). Simulador de localización en interiores basado
en | RSSI | [Repositorio | de | código]. | GitHub.
https://github.com/jrugeles/RSSI
[6] Trilateration vs. Triangulation for Indoor Positioning Systems | IoT
For All. (n.d.). IoT for All. https://www.iotforall.com/trilateration-vs-triangulation-indoor-positioning-s
[7] Tinker Tech Trove. (2021, April 17). Raspberry Pi Pico: nRF24L01
over | | SPI | [Video]. | | YouTube.
https://www.youtube.com/watch?v=aP8rSN-1eT0

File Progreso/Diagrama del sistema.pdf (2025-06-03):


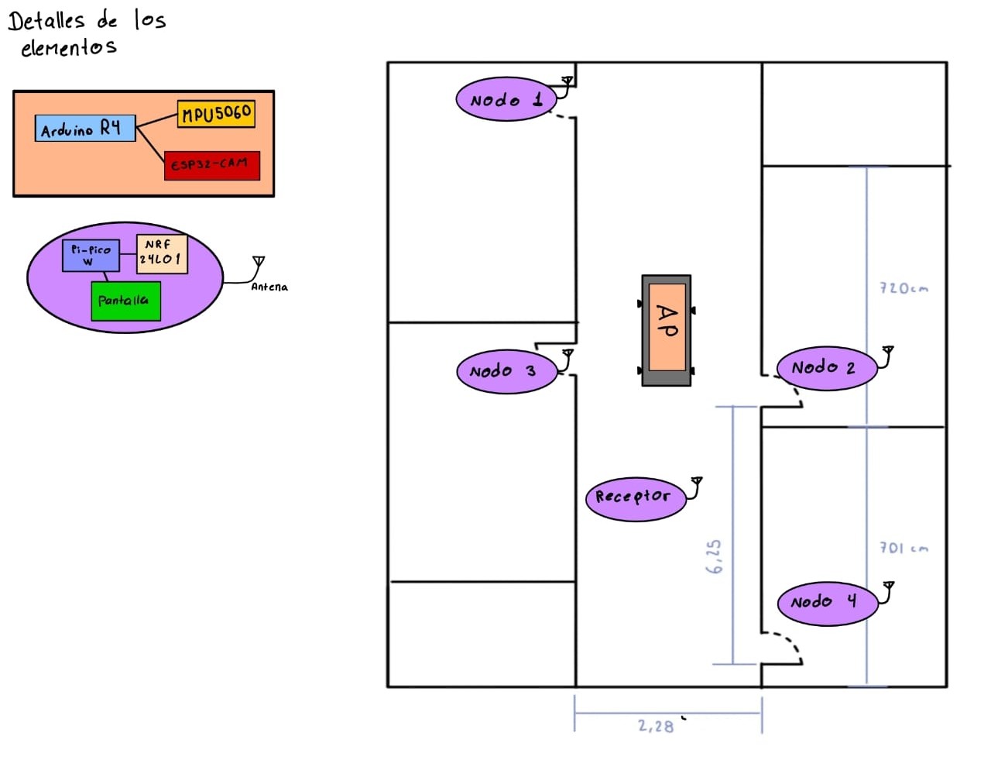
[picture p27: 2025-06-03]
Progreso/Diagrama presentación.jpg

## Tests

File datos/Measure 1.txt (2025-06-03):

Distancia (m)	RSSI TX1 (dB)	RSSI TX2 (dB)  RSSI TX3 (dB)	RSSI TX4 (dB)
0		-40		-52		-52		-42
1		-57		-57		-62		-65
2		-68		-58		-73		-70
3		-70		-67		-68		-72
4		-74		-72		-72		-70
5		-76		-81		-79		-78
6		-70		-80		-83		-75
7		-75		-85		-75		-80
8		-82		-82		-82		-71
9		-76		-83		-89		-72
10		-77		-77		-75		-72
11		-80		-87		-80		-78
12		-74		-71		-70		-76
13		-61		-76		-67		-70
14		-66		-73		-75		-70
15		-69		-71		-70		-80
16		-68		-75		-68		-72
17		-66		-77		-66		-73
18		-75		-80		-74		-70
19		-75		-82		-84		-84
20		-81		-84		-82		-75
21		-76		-79		-77		-74
22		-76		-84		-85		-76
23		-80		-83		-88		-81
24		-80		-74		-77		-79
25		-73		-77		-78		-76
26		-76		-89		-89		-90
27		-84		-87		-83		-82
28		-84		-83		-83		-85
29		-71		-80		-77		-84
30		-90		-93		-95		-87
31		-85		-93		-94		-86
32		-91		-95		-94		-90
33		-95		-94		-100		-96

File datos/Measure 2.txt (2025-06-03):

Distancia (m)	RSSI TX1 (dB)	RSSI TX2 (dB)	RSSI TX3 (dB)	RSSI TX4 (dB)
0		-29		-46		-44		-29
1		-55		-47		-55		-46
2		-57		-67		-57		-56
3		-69		-70		-67		-52
4		-69		-67		-67		-69
5		-72		-76		-76		-68
6		-76		-76		-76		-72
7		-74		-73		-76		-75
8		-76		-71		-100		-79
9		-82		-77		-100		-82
10		-80		-83		-100		-69
11		-74		-81		-100		-72
12		-82		-81		-100		-82
13		-80		-73		-100		-82
14		-70		-76		-100		-71
15		-75		-73		-100		-68
16		-86		-71		-100		-76
17		-80		-80		-100		-73
18		-74		-75		-100		-74
19		-86		-94		-100		-76
20		-87		-85		-100		-92
21		-96		-93		-100		-97
22		-100		-96		-100		-100
23		-100		-100		-100		-100
24		-100		-100		-100		-100
25		-100		-100		-100		-100
26		-100		-100		-100		-100
27		-100		-100		-100		-100
28		-100		-100		-100		-100
29		-100		-100		-100		-100
30		-100		-100		-100		-100
31		-100		-100		-100		-100
32		-100		-100		-100		-100
33		-100		-100		-100		-100

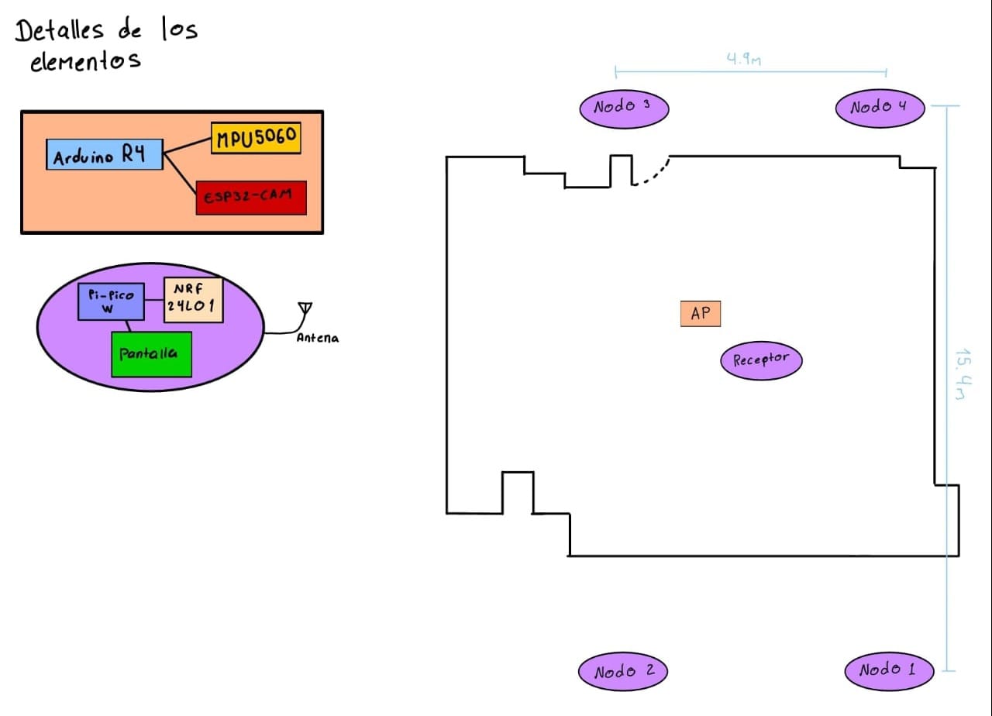
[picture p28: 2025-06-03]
Progreso/Diagrama pruebas.jpg

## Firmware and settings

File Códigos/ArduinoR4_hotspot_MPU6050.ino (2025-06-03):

#include <WiFiS3.h>
#include <ArduinoJson.h>
#include <Wire.h>
#include <MPU6050.h>
#include <math.h>

// Includes específicos para Arduino R4 WiFi (ARM Cortex-M4)
extern "C" char* sbrk(int incr);

// ========== CONFIGURACIÓN SISTEMA ==========
const char* ssid = "ArduinoR4-123456";
const char* password = "12345678";
WiFiServer server(80);
MPU6050 mpu;

// Constantes optimizadas
#define MAX_CLIENTES 10                  // Reducido para mejor rendimiento
#define TIMEOUT_HTTP 3000               // Timeout más corto
#define SENSOR_FREQ_HZ 50               // 50Hz para mejor respuesta
#define SENSOR_INTERVAL_MS (1000/SENSOR_FREQ_HZ)
#define WIFI_SCAN_INTERVAL 15000        // Escaneo menos frecuente
#define REPORT_INTERVAL 2000            // Reportes cada 2 segundos
#define MAX_RECONNECT_ATTEMPTS 3        // Intentos de reconexión
#define KALMAN_Q 0.001f                 // Ruido del proceso
#define KALMAN_R 0.01f                  // Ruido de medición

// Tipos de dispositivos
enum DeviceType { WIFI_ONLY, HTTP_CLIENT, UNKNOWN_DEVICE };

// ========== ESTRUCTURAS DE DATOS ==========
struct KalmanFilter {
  float q;      // Ruido del proceso
  float r;      // Ruido de medición  
  float x;      // Valor estimado
  float p;      // Error de estimación
  float k;      // Ganancia de Kalman
};

struct SensorData {
  float accelX, accelY, accelZ;         // Aceleración (g)
  float gyroX, gyroY, gyroZ;            // Velocidad angular (°/s)
  float pitch, roll;                    // Ángulos calculados (°)
  unsigned long timestamp;
  bool valido;
  uint8_t calidad;                      // 0-100%
};

struct ClientInfo {
  IPAddress ip;
  unsigned long lastSeen;
  unsigned long firstSeen;
  uint16_t requests;
  DeviceType type;
  String deviceName;
  float avgResponseTime;
  bool active;
};

struct SystemMetrics {
  unsigned long totalRequests;
  unsigned long errors404;
  unsigned long sensorErrors;
  unsigned long uptime;
  float cpuLoad;
  uint16_t freeMemory;
  uint8_t clientCount;
};

// ========== VARIABLES GLOBALES ==========
SensorData sensor;
SystemMetrics metrics;
ClientInfo clients[MAX_CLIENTES];
KalmanFilter kalman_ax, kalman_ay, kalman_gx, kalman_gy;

// Control de tiempo optimizado
unsigned long lastSensorRead = 0;
unsigned long lastReport = 0;
unsigned long lastWifiScan = 0;
unsigned long lastCleanup = 0;
unsigned long systemStart;

// Estado del sensor
bool sensorAvailable = false;
bool calibrationComplete = false;
int16_t accel_offset[3] = {0, 0, 0};
int16_t gyro_offset[3] = {0, 0, 0};
uint8_t reconnectAttempts = 0;

// ========== OPTIMIZACIONES ADICIONALES ==========
#define ENABLE_WATCHDOG          // Habilitar watchdog para recuperación automática
#define ENABLE_DEEP_ANALYSIS     // Análisis avanzado de movimiento
#define ENABLE_DATA_LOGGING      // Logging de datos para análisis

// Buffer circular para datos históricos
#define HISTORY_SIZE 20
struct SensorHistory {
  SensorData buffer[HISTORY_SIZE];
  uint8_t index;
  uint8_t count;
  float avgAccelMagnitude;
  float avgGyroMagnitude;
  bool movementDetected;
};

SensorHistory history;

// Estados del sistema para mejor control
enum SystemState {
  STATE_INITIALIZING,
  STATE_CALIBRATING, 
  STATE_NORMAL,
  STATE_ERROR_RECOVERY,
  STATE_LOW_POWER
};

SystemState currentState = STATE_INITIALIZING;

// ========== FUNCIONES DE UTILIDAD ==========
void logInfo(const String& msg) {
  Serial.print(F("[INFO] "));
  Serial.println(msg);
}

void logError(const String& msg) {
  Serial.print(F("[ERROR] "));
  Serial.println(msg);
}

void logDebug(const String& msg) {
  #ifdef DEBUG_MODE
  Serial.print(F("[DEBUG] "));
  Serial.println(msg);
  #endif
}

// Inicializar filtro Kalman
void initKalman(KalmanFilter* kf, float q, float r) {
  kf->q = q;
  kf->r = r;
  kf->x = 0.0f;
  kf->p = 1.0f;
}

// Aplicar filtro Kalman
float applyKalman(KalmanFilter* kf, float measurement) {
  // Predicción
  kf->p += kf->q;
  
  // Actualización
  kf->k = kf->p / (kf->p + kf->r);
  kf->x += kf->k * (measurement - kf->x);
  kf->p *= (1.0f - kf->k);
  
  return kf->x;
}

// ========== INICIALIZACIÓN ==========
void setup() {
  Serial.begin(115200);
  delay(1000);
  
  logInfo(F("=== Arduino R4 MPU6050 Monitor v2.0 ==="));
  logInfo(F("Iniciando sistema optimizado..."));
  
  systemStart = millis();
  
  // Inicializar filtros Kalman
  initKalman(&kalman_ax, KALMAN_Q, KALMAN_R);
  initKalman(&kalman_ay, KALMAN_Q, KALMAN_R);
  initKalman(&kalman_gx, KALMAN_Q * 10, KALMAN_R * 10); // Más ruido para gyro
  initKalman(&kalman_gy, KALMAN_Q * 10, KALMAN_R * 10);
  
  // Inicializar I2C y MPU6050
  Wire.begin();
  Wire.setClock(400000); // 400kHz para mejor rendimiento
  
  if (initializeMPU6050()) {
    logInfo(F("✓ MPU6050 inicializado"));
    sensorAvailable = true;
    calibrateSensor();
  } else {
    logError(F("✗ MPU6050 no detectado"));
  }
  
  // Configurar WiFi AP
  setupWiFiAP();
  
  // Inicializar métricas
  memset(&metrics, 0, sizeof(metrics));
  memset(clients, 0, sizeof(clients));
  
  logInfo(F("✓ Sistema listo"));
  logInfo("Conecta a WiFi: " + String(ssid));
  logInfo("Accede a: http://192.168.4.1");
  logInfo(F("================================"));
}

bool initializeMPU6050() {
  mpu.initialize();
  
  if (!mpu.testConnection()) {
    return false;
  }
  
  // Configuración optimizada
  mpu.setFullScaleAccelRange(MPU6050_ACCEL_FS_4);    // ±4g para mejor sensibilidad
  mpu.setFullScaleGyroRange(MPU6050_GYRO_FS_500);    // ±500°/s
  mpu.setDLPFMode(MPU6050_DLPF_BW_42);               // Filtro 42Hz
  mpu.setRate(19);                                   // 50Hz (1000/(1+19))
  
  // Configurar interrupciones si es necesario
  mpu.setIntEnabled(0x01); // Data ready interrupt
  
  return true;
}

void setupWiFiAP() {
  logInfo(F("Configurando Access Point..."));
  
  WiFi.config(IPAddress(192, 168, 4, 1));
  
  if (WiFi.beginAP(ssid, password) != WL_AP_LISTENING) {
    logError(F("Error al crear AP"));
    while (true) delay(1000);
  }
  
  delay(2000); // Estabilización
  server.begin();
  
  logInfo("AP creado: " + String(ssid));
  logInfo("IP: " + WiFi.localIP().toString());
}

void calibrateSensor() {
  if (!sensorAvailable) return;
  
  logInfo(F("Iniciando calibración (5 segundos)..."));
  logInfo(F("Mantén el sensor inmóvil"));
  
  const int samples = 1000;
  long acc_sum[3] = {0, 0, 0};
  long gyro_sum[3] = {0, 0, 0};
  
  for (int i = 0; i < samples; i++) {
    int16_t ax, ay, az, gx, gy, gz;
    mpu.getMotion6(&ax, &ay, &az, &gx, &gy, &gz);
    
    acc_sum[0] += ax;
    acc_sum[1] += ay;
    acc_sum[2] += az;
    gyro_sum[0] += gx;
    gyro_sum[1] += gy;
    gyro_sum[2] += gz;
    
    if (i % 200 == 0) Serial.print(".");
    delay(3);
  }
  Serial.println();
  
  // Calcular offsets
  accel_offset[0] = acc_sum[0] / samples;
  accel_offset[1] = acc_sum[1] / samples;
  accel_offset[2] = (acc_sum[2] / samples) - 8192; // Compensar gravedad (±4g: 1g = 8192)
  
  gyro_offset[0] = gyro_sum[0] / samples;
  gyro_offset[1] = gyro_sum[1] / samples;
  gyro_offset[2] = gyro_sum[2] / samples;
  
  calibrationComplete = true;
  logInfo(F("✓ Calibración completada"));
}

// ========== BUCLE PRINCIPAL OPTIMIZADO ==========
void loop() {
  unsigned long now = millis();
  unsigned long loopStart = micros();
  
  // Máquina de estados mejorada
  switch (currentState) {
    case STATE_INITIALIZING:
      if (sensorAvailable && calibrationComplete) {
        currentState = STATE_NORMAL;
        logInfo(F("Sistema iniciado correctamente"));
      }
      break;
      
    case STATE_CALIBRATING:
      // La calibración se maneja en la función específica
      break;
      
    case STATE_NORMAL:
      // Leer sensor a frecuencia fija
      if (now - lastSensorRead >= SENSOR_INTERVAL_MS) {
        if (sensorAvailable) {
          readSensorOptimized();
          addToHistory(sensor); // Agregar al historial
        } else {
          currentState = STATE_ERROR_RECOVERY;
        }
        lastSensorRead = now;
      }
      break;
      
    case STATE_ERROR_RECOVERY:
      attemptSensorRecovery();
      break;
      
    case STATE_LOW_POWER:
      // Modo de bajo consumo (futuras implementaciones)
      delay(100);
      break;
  }
  
  // Procesar clientes web
  processWebClients();
  
  // Tareas periódicas con intervalos optimizados
  if (now - lastReport >= REPORT_INTERVAL) {
    updateSystemMetrics();
    optimizeMemoryUsage(); // Optimización de memoria
    lastReport = now;
  }
  
  if (now - lastWifiScan >= WIFI_SCAN_INTERVAL) {
    scanWiFiClients();
    lastWifiScan = now;
  }
  
  if (now - lastCleanup >= 30000) { // Limpieza cada 30s
    cleanupInactiveClients();
    lastCleanup = now;
  }
  
  // Calcular carga CPU
  unsigned long loopTime = micros() - loopStart;
  metrics.cpuLoad = (metrics.cpuLoad * 0.95f) + (loopTime / 1000.0f * 0.05f);
}

void readSensorOptimized() {
  if (!sensorAvailable) {
    // Intentar reconectar
    if (reconnectAttempts < MAX_RECONNECT_ATTEMPTS) {
      if (initializeMPU6050()) {
        logInfo(F("✓ Sensor reconectado"));
        sensorAvailable = true;
        reconnectAttempts = 0;
      } else {
        reconnectAttempts++;
      }
    }
    
    // Datos por defecto si no hay sensor
    sensor.valido = false;
    sensor.calidad = 0;
    return;
  }
  
  int16_t ax, ay, az, gx, gy, gz, temp;
  
  // Leer datos crudos
  mpu.getMotion6(&ax, &ay, &az, &gx, &gy, &gz);
  temp = mpu.getTemperature();
  
  // Verificar validez de datos
  if (ax == 0 && ay == 0 && az == 0) {
    metrics.sensorErrors++;
    sensor.valido = false;
    sensor.calidad = 0;
    sensorAvailable = false; // Marcar para reconexión
    return;
  }
  
  // Aplicar calibración
  if (calibrationComplete) {
    ax -= accel_offset[0];
    ay -= accel_offset[1];
    az -= accel_offset[2];
    gx -= gyro_offset[0];
    gy -= gyro_offset[1];
    gz -= gyro_offset[2];
  }
  
  // Convertir a unidades físicas (±4g: 1g = 8192 LSB)
  float accelX_raw = (float)ax / 8192.0f;
  float accelY_raw = (float)ay / 8192.0f;
  float accelZ_raw = (float)az / 8192.0f;
  
  // Convertir giroscopio (±500°/s: 1°/s = 65.5 LSB)
  float gyroX_raw = (float)gx / 65.5f;
  float gyroY_raw = (float)gy / 65.5f;
  float gyroZ_raw = (float)gz / 65.5f;
  
  // Aplicar filtros Kalman
  sensor.accelX = applyKalman(&kalman_ax, accelX_raw);
  sensor.accelY = applyKalman(&kalman_ay, accelY_raw);
  sensor.accelZ = accelZ_raw; // Z sin filtrar para detección de gravedad
  
  sensor.gyroX = applyKalman(&kalman_gx, gyroX_raw);
  sensor.gyroY = applyKalman(&kalman_gy, gyroY_raw);
  sensor.gyroZ = gyroZ_raw;
    // Calcular ángulos (pitch y roll)
  sensor.pitch = atan2(sensor.accelY, sqrt(sensor.accelX * sensor.accelX + sensor.accelZ * sensor.accelZ)) * 180.0f / PI;
  sensor.roll = atan2(-sensor.accelX, sensor.accelZ) * 180.0f / PI;

  // Calcular calidad de la señal
  float accel_magnitude = sqrt(sensor.accelX * sensor.accelX + 
                              sensor.accelY * sensor.accelY + 
                              sensor.accelZ * sensor.accelZ);

  // Calidad basada en qué tan cerca está la magnitud total a 1g
  float quality_factor = 1.0f - abs(accel_magnitude - 1.0f);
  sensor.calidad = constrain(quality_factor * 100.0f, 0, 100);

  sensor.timestamp = millis();
  sensor.valido = true;
}

void processWebClients() {
  WiFiClient client = server.available();
  if (!client) return;
  
  unsigned long clientStart = millis();
  String request = readHTTPRequest(client);
  
  if (request.length() > 0) {
    String userAgent = extractUserAgent(client);
    registerClient(client.remoteIP(), userAgent);
    
    bool processed = routeRequest(client, request);
    if (processed) {
      metrics.totalRequests++;
      updateResponseTime(client.remoteIP(), millis() - clientStart);
    }
  }
  
  client.stop();
}

String readHTTPRequest(WiFiClient& client) {
  String request = "";
  unsigned long timeout = millis() + 1000; // 1 segundo timeout
  
  while (client.connected() && millis() < timeout) {
    if (client.available()) {
      String line = client.readStringUntil('\n');
      line.trim();
      
      if (line.length() == 0) break; // Fin de headers
      if (request == "") request = line; // Primera línea = request
    }
  }
  
  return request;
}

String extractUserAgent(WiFiClient& client) {
  // Implementación simplificada - en versión real habría que leer headers
  return "Unknown";
}

bool routeRequest(WiFiClient& client, const String& request) {
  if (request.indexOf("GET / ") >= 0) {
    sendMainPage(client);
    return true;
  } else if (request.indexOf("GET /data") >= 0) {
    sendSensorData(client);
    return true;
  } else if (request.indexOf("GET /status") >= 0) {
    sendSystemStatus(client);
    return true;
  } else if (request.indexOf("GET /calibrate") >= 0) {
    sendCalibrateResponse(client);
    return true;
  } else {
    send404(client);
    metrics.errors404++;
    return false;
  }
}

void sendSensorData(WiFiClient& client) {
  client.println(F("HTTP/1.1 200 OK"));
  client.println(F("Content-Type: application/json"));
  client.println(F("Access-Control-Allow-Origin: *"));
  client.println(F("Cache-Control: no-cache"));
  client.println();
    // Usar JsonDocument para compatibilidad con ArduinoJson v7
  JsonDocument doc;
    doc["accelX"] = round(sensor.accelX * 1000) / 1000.0;
  doc["accelY"] = round(sensor.accelY * 1000) / 1000.0;
  doc["accelZ"] = round(sensor.accelZ * 1000) / 1000.0;
  doc["gyroX"] = round(sensor.gyroX * 10) / 10.0;
  doc["gyroY"] = round(sensor.gyroY * 10) / 10.0;
  doc["gyroZ"] = round(sensor.gyroZ * 10) / 10.0;
  doc["pitch"] = round(sensor.pitch * 10) / 10.0;
  doc["roll"] = round(sensor.roll * 10) / 10.0;
  doc["timestamp"] = sensor.timestamp;
  doc["valido"] = sensor.valido;
  doc["calidad"] = sensor.calidad;
  doc["sensorConectado"] = sensorAvailable;
  
  String json;
  serializeJson(doc, json);
  client.print(json);
}

void sendSystemStatus(WiFiClient& client) {
  client.println(F("HTTP/1.1 200 OK"));
  client.println(F("Content-Type: application/json"));
  client.println(F("Access-Control-Allow-Origin: *"));
  client.println();

  JsonDocument doc;
  
  doc["uptime"] = millis() - systemStart;
  doc["totalRequests"] = metrics.totalRequests;
  doc["errors404"] = metrics.errors404;
  doc["sensorErrors"] = metrics.sensorErrors;
  doc["cpuLoad"] = round(metrics.cpuLoad * 10) / 10.0;
  doc["freeMemory"] = getFreeMemory();
  doc["clientCount"] = getActiveClientCount();
  doc["sensorAvailable"] = sensorAvailable;
  doc["calibrationComplete"] = calibrationComplete;
  doc["macAddress"] = getMacAddress();
  
  JsonArray clientArray = doc.createNestedArray("clients");
  for (int i = 0; i < MAX_CLIENTES; i++) {
    if (clients[i].active) {
      JsonObject clientObj = clientArray.createNestedObject();
      clientObj["ip"] = clients[i].ip.toString();
      clientObj["requests"] = clients[i].requests;
      clientObj["lastSeen"] = millis() - clients[i].lastSeen;
      clientObj["device"] = clients[i].deviceName;
    }
  }
  
  String json;
  serializeJson(doc, json);
  client.print(json);
}
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

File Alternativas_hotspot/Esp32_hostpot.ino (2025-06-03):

/*
 * Código combinado mejorado para ESP32 con sensor MPU6050 y Punto de Acceso WiFi
 * Incluye calibración, filtrado mejorado y manejo de deriva
 * Crea un punto de acceso WiFi para compartir los datos y recibir RSSI
 */

#include <WiFi.h>
#include <DNSServer.h>
#include <esp_wifi.h>
#include <tcpip_adapter.h>
#include <WebServer.h>
#include <ArduinoJson.h>
#include "I2Cdev.h"
#include "MPU6050.h"
#include "Wire.h"

// Configuración de red
const char* ssid = "ESP32-123456";
const char* password = "12345678";
const int maxClientes = 20;
const int canal = 1;
const bool ocultarRed = false;
const IPAddress ip(192, 168, 4, 1);

// DNS cautivo
DNSServer dnsServer;
const byte DNS_PORT = 53;

// Servidor web HTTP
WebServer server(80);

// Variables de monitoreo WiFi
unsigned long ultimoTiempoWiFi = 0;
const unsigned long intervaloWiFi = 5000;  // 5 segundos

// Declaración del objeto MPU6050
MPU6050 mpu;

// Variables para almacenar los datos del sensor
int16_t ax, ay, az;
int16_t gx, gy, gz;

// Variables para mediciones
float accelX, accelY;               // Aceleración en m/s²
float velocX = 0, velocY = 0;        // Velocidad en m/s
float offsetX = 0, offsetY = 0;      // Offsets de calibración
bool calibrated = false;             // Bandera de calibración

// Constantes de configuración para el MPU6050
const float accelFactor = 9.81 / 16384.0; // Conversión a m/s² (±2g)
const int CALIBRATION_SAMPLES = 500;      // Muestras para calibración
const float noiseThreshold = 0.05;        // Umbral de ruido en m/s²
const float decayFactor = 0.9;            // Factor de decaimiento
const int sampleRate = 50;                // Tiempo entre muestras (ms)

// Variables de tiempo
unsigned long tiempoAnterior = 0;
unsigned long deltaT = 0;

// Variables para compartir datos del sensor
unsigned long ultimoTiempoSensor = 0;
const unsigned long intervaloSensor = 1000;  // 1 segundo

// ========= SETUP =========
void setup() {
  Serial.begin(115200);
  delay(1000);
  Serial.println("\n===========================");
  Serial.println("Iniciando sistema combinado mejorado...");

  // Inicializar I2C y MPU6050
  Serial.println("Inicializando I2C...");
  Wire.begin();
  
  Serial.println("Inicializando MPU6050...");
  mpu.initialize();
  
  // Verificar la conexión
  Serial.println("Probando conexión con el MPU6050...");
  Serial.print("MPU6050 conexión: ");
  Serial.println(mpu.testConnection() ? "OK" : "FALLO");
  
  // Configuración del rango de acelerómetro a ±2g
  mpu.setFullScaleAccelRange(0); // 0 = ±2g
  
  Serial.println("Calibrando sensor... Mantenga el dispositivo inmóvil.");
  // Realizar la calibración
  calibrateSensor();
  
  tiempoAnterior = millis();
  
  // Configurar como AP
  WiFi.mode(WIFI_AP);

  // Ajustes avanzados del AP
  wifi_config_t conf;
  esp_wifi_get_config(WIFI_IF_AP, &conf);
  conf.ap.beacon_interval = 100;
  conf.ap.authmode = WIFI_AUTH_WPA2_PSK;
  esp_wifi_set_config(WIFI_IF_AP, &conf);
  esp_wifi_set_max_tx_power(82);

  WiFi.softAPConfig(ip, ip, IPAddress(255, 255, 255, 0));

  if (WiFi.softAP(ssid, password, canal, ocultarRed, maxClientes)) {
    Serial.println("¡AP iniciado correctamente!");
    Serial.print("IP del AP: ");
    Serial.println(WiFi.softAPIP());
    dnsServer.start(DNS_PORT, "*", ip);

    uint8_t mac[6];
    WiFi.softAPmacAddress(mac);
    Serial.printf("MAC del AP: %02X:%02X:%02X:%02X:%02X:%02X\n",
                  mac[0], mac[1], mac[2], mac[3], mac[4], mac[5]);
  } else {
    Serial.println("ERROR: Fallo al iniciar el AP. Reiniciando...");
    ESP.restart();
  }

  // Configurar servidor web
  server.on("/", HTTP_GET, handleRoot);
  server.on("/rssi", HTTP_POST, handleRSSI);
  server.on("/data", HTTP_GET, handleSensorData);
  server.on("/clients", HTTP_GET, handleClientData);
  server.onNotFound(handleNotFound);
  server.begin();
  Serial.println("Servidor HTTP iniciado");
  Serial.println("Rutas disponibles: /, /rssi, /data, /clients");
  Serial.println("===========================");
}

void handleSensorData() {
  StaticJsonDocument<200> doc;
  
  doc["accelX"] = accelX;
  doc["accelY"] = accelY;
  doc["velocX"] = velocX;
  doc["velocY"] = velocY;
  
  String jsonResponse;
  serializeJson(doc, jsonResponse);
  
  server.send(200, "application/json", jsonResponse);
  Serial.println("Enviando datos del sensor por HTTP");
}

// ========= LOOP =========
void loop() {
  // Procesar solicitudes DNS y HTTP
  dnsServer.processNextRequest();
  server.handleClient();

  // Gestionar clientes WiFi y monitoreo
  unsigned long tiempoActual = millis();
  if (tiempoActual - ultimoTiempoWiFi >= intervaloWiFi) {
    ultimoTiempoWiFi = tiempoActual;
    gestionClientes();
    mostrarInfoClientes();
  }
  
  // Leer datos del sensor MPU6050
  leerDatosMPU();
}

// ========= Funciones MPU6050 =========

// Función para calibrar el sensor
void calibrateSensor() {
  float sumX = 0, sumY = 0;
  
  for(int i = 0; i < CALIBRATION_SAMPLES; i++) {
    mpu.getAcceleration(&ax, &ay, &az);
    sumX += ax;
    sumY += ay;
    delay(5);
    
    // Mostrar progreso cada 100 muestras
    if(i % 100 == 0) {
      Serial.print("Calibrando... ");
      Serial.print((i * 100) / CALIBRATION_SAMPLES);
      Serial.println("%");
    }
  }
  
  offsetX = sumX / CALIBRATION_SAMPLES;
  offsetY = sumY / CALIBRATION_SAMPLES;
  calibrated = true;
  
  Serial.println("Calibración completada.");
  Serial.print("Offsets calculados - X: ");
  Serial.print(offsetX);
  Serial.print(", Y: ");
  Serial.println(offsetY);
}

// Función para actualizar la velocidad con filtrado mejorado
void updateVelocity(float deltaT) {
  // Eje X
  if(abs(accelX) > noiseThreshold) {
    velocX += accelX * deltaT;
  } else {
    velocX *= decayFactor;
    // Forzar a cero cuando sea muy pequeño
    if(abs(velocX) < 0.01) velocX = 0;
  }
  
  // Eje Y
  if(abs(accelY) > noiseThreshold) {
    velocY += accelY * deltaT;
  } else {
    velocY *= decayFactor;
    // Forzar a cero cuando sea muy pequeño
    if(abs(velocY) < 0.01) velocY = 0;
  }
}
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

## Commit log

2025-05-14 Create ESP32_MPU6050_Basic.ino
    Tester modulo MPU6050 versión Alpha, calcula velocidad y aceleración
2025-05-14 Create Esp32_hotspot.ino
    Crea un hotspot que indica los clientes con direccion ip y direccion mac, ademas tiene potencial como servidor web http
